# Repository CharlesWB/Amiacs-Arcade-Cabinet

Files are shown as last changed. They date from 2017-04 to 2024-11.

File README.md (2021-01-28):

# Amiacs Arcade Cabinet

My adventures in creating a custom arcade cabinet.

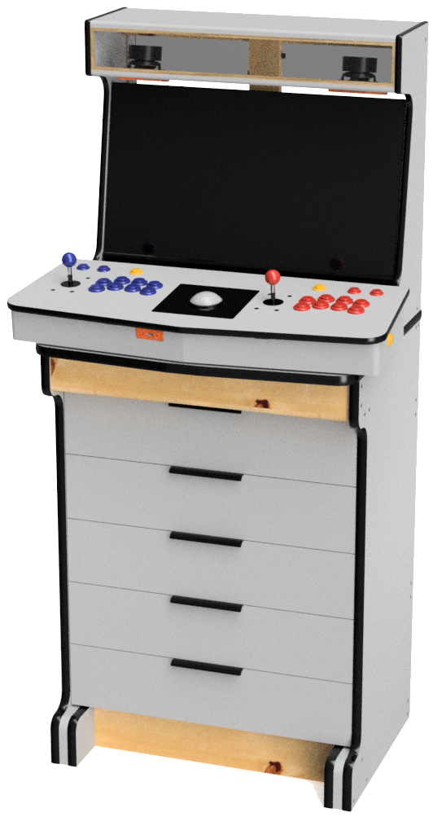
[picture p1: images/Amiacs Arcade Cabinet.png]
Model of Amiacs Arcade Cabinet


## License

The cabinet of this project is licensed under the [Creative Commons Attribution-NonCommercial-ShareAlike 4.0 International (CC BY-NC-SA 4.0) license](https://creativecommons.org/licenses/by-sa/4.0/), and the source code is licensed under the [MIT license](http://opensource.org/licenses/mit-license.php).

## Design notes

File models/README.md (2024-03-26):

# Models

This folder contains various "models" used to create the Amiacs arcade cabinet. Such as 3D models, artwork, and Fritzing diagrams.

## Amiacs Arcade Cabinet Prototype.skp

3D CAD model of the original prototype cabinet. Created using [SketchUp](https://www.sketchup.com/).

## Amiacs Arcade Cabinet v32.step

A STEP file format export of the CAD model prior to the removal of the export functionality from the personal version of AutoDesk Fusion 360. This export occurred at v32 of the Fusion 360 model.

## Amiacs Arcade.fzz

Fritzing diagram representing the wiring of all the components in the cabinet. Created using [Fritzing](https://fritzing.org/).

## Button Labels.svg

Vector images for the labels that are placed directly on the control panel buttons. Created using [Inkscape](https://inkscape.org/).

### Fonts Used

* [Game Played](https://www.dafont.com/game-played.font) for button text.
* [Restroom](https://www.dafont.com/restroom.font) for one and two player button labels (character 'G').
* [Fire](https://www.dafont.com/fire.font) for hotkey button symbol (character 't').

In Inkscape, Document Resources also has a list of the fonts used in the file.

### Usage

* Designed for import to [Cricut Design Space](https://cricut.com/) for cutting.
* Cut from black vinyl with adhesive backing.
* The circle of each label is used for aligning the text on the actual button.

*Cricut Design Space Import*

1. In Inkscape, select all text objects and use Path -> Object to Path.
    * Cricut Design Space didn't import text objects.
    * Use Ctrl to select into a group.
2. Upload as image to Cricut Design Space.
3. Change size of top level group to match Inkscape size.
    * Not sure why size is incorrect. Possibly due to metric/inch scaling.
    * Technically Inkscape size is .1 mm larger due to stroke thickness.
4. Ungroup top level group.
5. Select each button label group and Attach to keep the shapes together.

## Cabinet Artwork.svg

Vector image used for describing the cabinet graphics. Created using [Inkscape](https://inkscape.org/).

### Fonts Used

* [Game Played](https://www.dafont.com/game-played.font) for button text and console labels.
* [Fire](https://www.dafont.com/fire.font) for hotkey button symbol (character 't')
* [Aurebesh](https://www.dafont.com/aurebesh.font) for the secret names.
* [Back to the Future 2002](https://www.dafont.com/back-to-the-future.font) for the representation of the logo on the marquee. This is not meant to be the final look.
* Arial for drawing notes and reference dimensions.

In Inkscape, Document Resources also has a list of the fonts used in the file.

## Cabinet Labels.svg

Vector images of various labels placed on the cabinet. Created using [Inkscape](https://inkscape.org/).

### Fonts Used

* Arial for all text.

In Inkscape, Document Resources also has a list of the fonts used in the file.

### Usage

I'm using an adhesive backed vinyl. Trying to get the best durability and adhesion.

## Test Amiacs Light Controller.fzz

Fritzing breadboard diagram for testing the various LEDs of the cabinet. Created using [Fritzing](https://fritzing.org/).

## Test MCP23017 Arcade Button LEDs.fzz

Fritzing breadboard diagram for testing control of the button LEDs using an MCP23017. Created using [Fritzing](https://fritzing.org/).

This was an early prototype for controlling multiple LEDs using two pins on the Arduino. This is not used in the current cabinet design.

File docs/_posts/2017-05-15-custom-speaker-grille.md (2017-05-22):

---
layout: post
title:  "Custom Speaker Grille"
date:   2017-05-15 18:00:00
excerpt_separator: <!--more-->
---
When I bought the small 3" (78 mm) [speakers](http://a.co/ejMOJVP) I hadn't found a speaker grille that would fit.
Every once in a while I'd look but the smallest I could find was 3.5" (90 mm).

I had recently purchased a [3D printer](http://a.co/9hegcnT) and I realized that I finally had a practical use for it.
<!--more-->

I created a 3D printable speaker grille. Nothing fancy, a rectangular part with four mounting holes and a lot
of holes in a circular pattern. It's a component in the
[SketchUp model]({{ site.github.repository_url }}/tree/master/models/).

3D printing is still new to me so getting that first layer to stick took some work. Especially all those circles.
It wasn't perfect but eventually I printed on a glass sheet which gave me a very smooth surface finish.
Even though nobody really sees it given where it is on the cabinet.

The parameters I used to print it are: 0.2 mm layer height, 0.8 mm wall thickness, and 20% infill.

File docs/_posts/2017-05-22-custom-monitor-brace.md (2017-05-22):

---
layout: post
title:  "Custom Monitor Brace"
date:   2017-05-22 16:45:00
excerpt_separator: <!--more-->
---
As I noted in a previous post the monitor mount works fine, but because it only holds the monitor at the bottom
the top of the monitor can move around.
<!--more-->

At the time I did a quick fix by placing a piece of MDF behind the top of the monitor. This would stop
the monitor from being pushed too far back. (Because I know the kids will touch the monitor to point
at things.) This piece is not shown in the
[SketchUp model]({{ site.github.repository_url }}/tree/master/models/).

This still allowed the monitor the move forward and side to side so I tried an even cheaper fix by pushing foam
around the top corners. It worked well enough to get through play testing.

Now that I have a 3D printer I designed a custom corner brace. One each at the top corners holds the monitor in place.
No more flopping around. Like the custom speaker grille it's a component in the SketchUp model.

The parameters I used to print it are: 0.2 mm layer height, 0.8 mm wall thickness, and 20% infill.

This cabinet still has the piece of MDF at the center of the monitor so I don't know yet if that's actually needed.
Maybe with a future build I'll leave that out and try it.

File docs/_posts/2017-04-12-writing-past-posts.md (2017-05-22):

---
layout: post
title:  "Writing Past Posts"
date:   2017-04-12 18:00:00
---
I started this project several months ago. And at the time I did not write any posts.
I didn't even have this blog/Github project.
I've decided to go back in time and write those posts.

So over the coming weeks (or months) you'll see me creating those past posts as well as current posts.

Hopefully that's not too confusing. Because current posts may reference the as yet unwritten past posts.
I'm sure it'll work out in the end.

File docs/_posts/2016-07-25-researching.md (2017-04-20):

---
layout: post
title:  "Researching"
date:   2016-07-25 12:00:00
excerpt_separator: <!--more-->
---
Okay, so I want an 80's style arcade cabinet with buttons, joystick, trackball, and flashing lights.
What does that actually involve? Time to research what my options are.
<!--more-->

The pictures and discussions on [Coding Horror's post](https://blog.codinghorror.com/the-raspberry-pi-has-revolutionized-emulation/) defined most of my choices.

Here's the wishlist I came up with:
* Controls for two players. Fun for the whole family. At least two of them anyway.
* Buttons that light up. Flashing lights are required to make it feel like an arcade.
* Joysticks with ball shaped handle. Instead of the bat shape. Just because it looks right.
* Trackball. How else can you play Centipede?
* Trackball that lights up. Need more flashing lights.
* Steering wheel. How else can you play Outrun?
* Insert coin slots. For authenticity.
* Custom graphics. More authenticity.
* Bar top size. Trying for something semi-portable.

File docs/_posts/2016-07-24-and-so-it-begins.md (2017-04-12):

---
layout: post
title:  "And So It Begins..."
date:   2016-07-24 12:00:00
---
Years ago I thought about building a MAME arcade machine. Which at the time meant a big, boxy computer and a big, boxy CRT monitor. I never got around to it.

Then Coding Horror wrote his post about [Raspberry Pi revolutionizing emulation](https://blog.codinghorror.com/the-raspberry-pi-has-revolutionized-emulation/).
Suddenly the desire to relive all those 80's arcade games came back. And to have an actual 80's style arcade cabinet.
Buttons, joystick, trackball, flashing lights, the whole works.

And so it begins...

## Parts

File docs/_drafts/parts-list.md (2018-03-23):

---
layout: post
title:  "Parts List"
date:   2018-02-25 12:00:00
---
|Part|Link|Cost|
|---|---|---|
|Electric ICE-T™ Deluxe RGB Arcade Trackball V2.5|http://groovygamegear.com/webstore/index.php?main_page=product_info&cPath=74&products_id=270|$116.95|
|Trackball Mounting Kit - 3"|http://groovygamegear.com/webstore/index.php?main_page=product_info&cPath=74&products_id=314|$13.95|
|CanaKit Raspberry Pi 3 with 2.5A Micro USB Power Supply|http://a.co/fu1tPRN|$42.99|
|Micro SD Card 32 GB||$13.00|
|Acer R240HY bidx 23.8-Inch IPS Monitor|http://a.co/5v14bSI|$129.99|

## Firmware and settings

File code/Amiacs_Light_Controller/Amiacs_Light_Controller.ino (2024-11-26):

/*
Ideas:
- I2C command data and related methods could be a separate class.
- The player buttons flicker when using FastLED.show() and no changes were made.
  Is that an error in TLC5947SingleColorController or normal? Right now this code gets
  around this by not calling show() when no colors change.
*/

#define FASTLED_INTERNAL

#include <Adafruit_TLC5947.h>
#include <FastLED.h>
#include <Wire.h>
#include "SingleTriColorLEDController.h"
#include "TLC5947SingleColorController.h"


// General definitions.
// Can only be 2. No other values have been implemented.
#define NUM_PLAYERS 2
// Can only be 1. No other values have been implemented.
#define NUM_TRACKBALLS 1
// Can only be 2. No other values have been implemented.
#define NUM_AMBIENT_LEDS 2


// Pin definitions.
#define PLAYER_LIGHTS_LATCH_PIN 10
#define PLAYER_LIGHTS_DATA_PIN 12
#define PLAYER_LIGHTS_CLOCK_PIN 13
#define PLAYER_LIGHTS_OUTPUT_ENABLE_PIN = 8
#define TRACKBALL_RED_PIN 3
#define TRACKBALL_GREEN_PIN 5
#define TRACKBALL_BLUE_PIN 6
#define MARQUEE_LIGHT_PIN 9
#define AMBIENT_LIGHT_DATA_PIN 11
#define AMBIENT_LIGHT_CLOCK_PIN 13
#define BRIGHTNESS_PIN A7


// Player button pin numbers for the Adafruit TLC5947.
#define NUM_PLAYER_LIGHTS 24
#define PLAYER1_LIGHT_B 0
#define PLAYER1_LIGHT_A 1
#define PLAYER1_LIGHT_Y 2
#define PLAYER1_LIGHT_X 3
#define PLAYER1_LIGHT_L2 4
#define PLAYER1_LIGHT_R2 5
#define PLAYER1_LIGHT_L1 6
#define PLAYER1_LIGHT_R1 7
#define PLAYER1_LIGHT_SELECT 8
#define PLAYER1_LIGHT_START 9
#define PLAYER1_LIGHT_COMMAND 10
#define PLAYER1_LIGHT_HOTKEY 11
#define PLAYER2_LIGHT_B 12
#define PLAYER2_LIGHT_A 13
#define PLAYER2_LIGHT_Y 14
#define PLAYER2_LIGHT_X 15
#define PLAYER2_LIGHT_L2 16
#define PLAYER2_LIGHT_R2 17
#define PLAYER2_LIGHT_L1 18
#define PLAYER2_LIGHT_R1 19
#define PLAYER2_LIGHT_SELECT 20
#define PLAYER2_LIGHT_START 21
#define PLAYER2_LIGHT_COMMAND 22
#define PLAYER2_LIGHT_HOTKEY 23

#define PLAYER_ALL_LIGHTS_LAYOUT_ROWS 3
#define PLAYER_ALL_LIGHTS_LAYOUT_COLUMNS 11
#define PLAYER1_ALL_LIGHTS_LAYOUT_COLUMNS 6
#define PLAYER2_ALL_LIGHTS_LAYOUT_COLUMNS 5

int playerAllLightLayout[PLAYER_ALL_LIGHTS_LAYOUT_ROWS][PLAYER_ALL_LIGHTS_LAYOUT_COLUMNS] =
{
  {-1, PLAYER1_LIGHT_SELECT, PLAYER1_LIGHT_START, PLAYER1_LIGHT_COMMAND, -1, -1, PLAYER2_LIGHT_COMMAND, -1, PLAYER2_LIGHT_SELECT, PLAYER2_LIGHT_START, -1},
  {-1, -1, PLAYER1_LIGHT_Y, PLAYER1_LIGHT_X, PLAYER1_LIGHT_L2, PLAYER1_LIGHT_R2, PLAYER2_LIGHT_Y, PLAYER2_LIGHT_X, PLAYER2_LIGHT_L2, PLAYER2_LIGHT_R2, -1},
  {PLAYER1_LIGHT_HOTKEY, -1, PLAYER1_LIGHT_B, PLAYER1_LIGHT_A, PLAYER1_LIGHT_L1, PLAYER1_LIGHT_R1, PLAYER2_LIGHT_B, PLAYER2_LIGHT_A, PLAYER2_LIGHT_L1, PLAYER2_LIGHT_R1, PLAYER2_LIGHT_HOTKEY}
};

#define PLAYER_PRIMARY_LIGHTS_LAYOUT_ROWS 2
#define PLAYER_PRIMARY_LIGHTS_LAYOUT_COLUMNS 8

int playerPrimaryLightLayout[PLAYER_PRIMARY_LIGHTS_LAYOUT_ROWS][PLAYER_PRIMARY_LIGHTS_LAYOUT_COLUMNS] =
{
  {PLAYER1_LIGHT_Y, PLAYER1_LIGHT_X, PLAYER1_LIGHT_L2, PLAYER1_LIGHT_R2, PLAYER2_LIGHT_Y, PLAYER2_LIGHT_X, PLAYER2_LIGHT_L2, PLAYER2_LIGHT_R2},
  {PLAYER1_LIGHT_B, PLAYER1_LIGHT_A, PLAYER1_LIGHT_L1, PLAYER1_LIGHT_R1, PLAYER2_LIGHT_B, PLAYER2_LIGHT_A, PLAYER2_LIGHT_L1, PLAYER2_LIGHT_R1}
};

// Although the color of the player lights is defined by the button plastic,
// for FastLED the player light color is white so that it is fully lit.
const CHSV playerLightColor = CHSV(0, 0, 255);

const CHSV defaultSystemColor = CHSV(24, 255, 255);
CRGB playerColors[NUM_PLAYERS] = {CRGB::Blue, CRGB::Red};
CHSV playerColorsHSV[NUM_PLAYERS] = {rgb2hsv_approximate(playerColors[0]), rgb2hsv_approximate(playerColors[1])};

// The intent for this palette is to cycle between the player colors.
CRGBPalette16 playerColorPalette = CRGBPalette16(
  playerColors[0], playerColors[0], playerColors[0], playerColors[0],
  playerColors[0], playerColors[0], playerColors[0], playerColors[0],
  playerColors[1], playerColors[1], playerColors[1], playerColors[1],
  playerColors[1], playerColors[1], playerColors[1], playerColors[1]
);

CRGB playerLights[NUM_PLAYER_LIGHTS];
CRGB trackballs[NUM_TRACKBALLS];
CRGB ambientLights[NUM_AMBIENT_LEDS];


// I2C communications between the Arduino and the Raspberry Pi.
// Data format:
// - 1 byte for the command. The command value is the same as the DisplayMode enum.
// - Data for game running display mode:
//   - 12 bytes for player 1 lights. In same order as Adafruit TLC5947 pins defined above. Non-zero value indicates light is on.
//   - 12 bytes for player 2 lights. In same order as Adafruit TLC5947 pins defined above. Non-zero value indicates light is on.
//   - 1 byte for trackball. Non-zero value indicates trackball light is on.
//   - 1 byte to indicate that the game has two separate player controls.
// Any additional data is read but ignored.
#define SLAVE_ADDRESS 0x07
#define COMMAND_ARRAY_SIZE NUM_PLAYER_LIGHTS + NUM_TRACKBALLS + 1
#define COMMAND_TRACKBALL_INDEX COMMAND_ARRAY_SIZE - 2
#define COMMAND_TWO_CONTROLS_INDEX COMMAND_ARRAY_SIZE - 1
byte command = 0;
byte commandData[COMMAND_ARRAY_SIZE];


// These values match what is found in Amiacs-Event-Processor.py.
enum DisplayMode {
  // Mode used while system starts.
  STARTING = 0,
  // Mode used when Emulation Station displays a screensaver.
  ATTRACT = 1,
  // Mode used when the Emulation Station is running.
  EMULATION_STATION = 2,
  // Mode used when a game system is running.
  GAME_RUNNING = 3,
};

DisplayMode displayMode = STARTING;

// For each DisplayMode, identify if an initialization must be done while running in loop.
// NOTE: This is manually sized to match the number of DisplayModes.
int initializeDisplayMode[] = {false, true, true, true};

// The attract DisplayMode has an additional initialization step for the brightness.
bool initializeAttractDisplayModeBrightness = true;

enum AttractDisplayMode {
  RANDOM_BLINK,
  CYLON,
  IN_TO_CENTER,
  NUM_ATTRACT_DISPLAY_MODES,
};

AttractDisplayMode attractDisplayMode = random8(NUM_ATTRACT_DISPLAY_MODES);


void setup() {
  Serial.begin(9600);

  // There's a short delay between when the Arduino starts and when the button
  // encoder and the Adafruit TLC5947 boards get power from the Raspberry Pi.
  // We'll wait for that so that the TLC5947 will be properly initialized.
  delay(5000);

  SetBrightness();

  SetupPlayerLights();
  SetupTrackballLights();
  SetupAmbientLights();
  SetupMarqueeLights();

  TestLightsDuringSetup();

  Wire.begin(SLAVE_ADDRESS);
  Wire.onReceive(CommandReceiveEvent);

  SetLightsToSystemDefaultColor();

  FastLED.show();
}

void loop() {
  switch(displayMode) {
    case STARTING:
      LoopStartingDisplayMode();
      break;
    case ATTRACT:
      LoopAttractDisplayMode();
      break;
    case EMULATION_STATION:
      LoopEmulationStationDisplayMode();
      break;
    case GAME_RUNNING:
      LoopGameRunningDisplayMode();
      break;
  }
}


// The display mode during startup is a type of attract mode.
// The lights are expected to have been turned on to their default colors prior to this.
// This will fade the brightness in and out at an increasing rate then pause before switching to Emulation Station mode.
// The typical time from power on to Emulation Station start is about one minute.
void LoopStartingDisplayMode() {
  static unsigned long startTime = millis();

  static unsigned long startingStepTimeline[] = {0, 5000, 9900, 14700, 19200, 23200, 26700, 29600, 31900, 33400, 34200, 34800, 35400, 36000, 36400, 45000};
  uint8_t stepCount = (sizeof(startingStepTimeline) / sizeof(startingStepTimeline[0]));

  SetBrightness();

  unsigned long now = millis() - startTime;
  uint8_t step = 0;
  for(uint8_t i = 0; i < stepCount; i++) {
    if(now > startingStepTimeline[i]) {
      step = i;
    }
  }

  if(step < stepCount - 2) {
    uint8_t frame = map(now, startingStepTimeline[step], startingStepTimeline[step + 1], 255, 0);

    // Offset the frame by 128 so that the brightness starts at 255.
    uint8_t brightness = quadwave8(frame + 128);

    if(playerLights[0] != CHSV(playerLightColor.hue, playerLightColor.sat, brightness)) {
      fill_solid(playerLights, NUM_PLAYER_LIGHTS, CHSV(playerLightColor.hue, playerLightColor.sat, brightness));
      fill_solid(trackballs, NUM_TRACKBALLS, CHSV(defaultSystemColor.hue, defaultSystemColor.sat, brightness));
      fill_solid(ambientLights, NUM_AMBIENT_LEDS, CHSV(defaultSystemColor.hue, defaultSystemColor.sat, brightness));
      FastLED.show();
      SetMarqueeBrightness(brightness);
    }
  }
  else if(step < stepCount - 1) {
    if(playerLights[0] != playerLightColor) {
      fill_solid(playerLights, NUM_PLAYER_LIGHTS, playerLightColor);
      fill_solid(trackballs, NUM_TRACKBALLS, defaultSystemColor);
      fill_solid(ambientLights, NUM_AMBIENT_LEDS, defaultSystemColor);
      FastLED.show();
    }
  }
  else {
    displayMode = EMULATION_STATION;
    initializeDisplayMode[EMULATION_STATION] = true;
  }
}

void LoopEmulationStationDisplayMode() {
  static unsigned long startTime = millis();

  SetBrightness();

  if(initializeDisplayMode[EMULATION_STATION]) {
    startTime = millis();

    EmulationStationDisplayModeInitialize();

    initializeDisplayMode[EMULATION_STATION] = false;
  }
}

void EmulationStationDisplayModeInitialize() {
  fill_solid(playerLights, NUM_PLAYER_LIGHTS, playerLightColor);

  playerLights[PLAYER1_LIGHT_L2] = CRGB::Black;
  playerLights[PLAYER1_LIGHT_R2] = CRGB::Black;
  playerLights[PLAYER1_LIGHT_COMMAND] = CRGB::Black;
  playerLights[PLAYER1_LIGHT_HOTKEY] = CRGB::Black;
  playerLights[PLAYER2_LIGHT_L2] = CRGB::Black;
  playerLights[PLAYER2_LIGHT_R2] = CRGB::Black;
  playerLights[PLAYER2_LIGHT_COMMAND] = CRGB::Black;
  playerLights[PLAYER2_LIGHT_HOTKEY] = CRGB::Black;

  fill_solid(trackballs, NUM_TRACKBALLS, CRGB::Black);

  fill_solid(ambientLights, NUM_AMBIENT_LEDS, defaultSystemColor);

  FastLED.show();
}

void LoopGameRunningDisplayMode() {
  SetBrightness();

  if(initializeDisplayMode[GAME_RUNNING]) {
    GameRunningDisplayModeInitialize();

    initializeDisplayMode[GAME_RUNNING] = false;
  }

  if(CommandIsTrackballOn() && CommandIsTwoControllerGame()) {
    CycleTrackballBetweenPlayerColors();
  }
}

void GameRunningDisplayModeInitialize() {
  for(int light = 0; light < NUM_PLAYER_LIGHTS; light++) {
    if(commandData[light] != 0) {
      playerLights[light] = playerLightColor;
    }
    else {
      playerLights[light] = CRGB::Black;
    }
  }

  if(CommandIsTrackballOn()) {
    fill_solid(trackballs, NUM_TRACKBALLS, playerColors[0]);
  }
  else {
    fill_solid(trackballs, NUM_TRACKBALLS, CRGB::Black);
  }

  fill_solid(ambientLights, NUM_AMBIENT_LEDS, defaultSystemColor);

  FastLED.show();
}

// Randomly alternate between the various attract display modes.
// Dim the lights over time. At a low level completely turn off the lights.
void LoopAttractDisplayMode() {
  const static unsigned long duration = 120000;
  const static unsigned long dimmingDuration = 2 * duration;

  static unsigned long startTime = millis();
  static unsigned long dimmingStartTime = millis();

  static float brightnessFactor = 1;

  if(initializeAttractDisplayModeBrightness) {
    dimmingStartTime = millis();

    brightnessFactor = 1;

    initializeAttractDisplayModeBrightness = false;
  }

  if(initializeDisplayMode[ATTRACT]) {
    startTime = millis();

    AttractDisplayModeInitialize();

    initializeDisplayMode[ATTRACT] = false;
  }

  if(brightnessFactor > .2) {
    SetBrightness(brightnessFactor);

    unsigned long dimmingNow = millis() - dimmingStartTime;
    if(dimmingNow > dimmingDuration) {
      brightnessFactor *= .6;
      dimmingStartTime = millis();
    }

    unsigned long now = millis() - startTime;
    if(now <= duration) {
      if(attractDisplayMode == RANDOM_BLINK) {
        AttractDisplayModeRandomBlink();
      }
      else if(attractDisplayMode == CYLON) {
        AttractDisplayModeCylon();
      }
      else if(attractDisplayMode == IN_TO_CENTER) {
        AttractDisplayModeInToCenter();
      }

      FastLED.show();
    }
    else {
      AttractDisplayMode nextAttractDisplayMode = random8(NUM_ATTRACT_DISPLAY_MODES);
      if(nextAttractDisplayMode != attractDisplayMode) {
        attractDisplayMode = nextAttractDisplayMode;
        initializeDisplayMode[ATTRACT] = true;
      }
    }
  }
  else {
    fill_solid(playerLights, NUM_PLAYER_LIGHTS, CRGB::Black);
    fill_solid(trackballs, NUM_TRACKBALLS, CRGB::Black);
    fill_solid(ambientLights, NUM_AMBIENT_LEDS, CRGB::Black);
    SetMarqueeBrightness(0);

    FastLED.show();
  }
}

void AttractDisplayModeInitialize() {
  fill_solid(playerLights, NUM_PLAYER_LIGHTS, CRGB::Black);
  fill_solid(trackballs, NUM_TRACKBALLS, CRGB::Black);
  fill_solid(ambientLights, NUM_AMBIENT_LEDS, CRGB::Black);

  FastLED.show();
}

// Cycle columns in to the center and back, fading out the other columns.
// Fade the trackball in sync with the cycle.
// Fade in and out each side of the ambient lights to match the cycling player colors.
void AttractDisplayModeInToCenter() {
  const static unsigned long duration = 2400;

  static unsigned long startTime = millis();

  unsigned long now = millis() - startTime;

  unsigned long elapsed = now - (duration * (now / duration));
  int player1Column = elapsed / (duration / (2 * PLAYER1_ALL_LIGHTS_LAYOUT_COLUMNS));
  if(player1Column >= PLAYER1_ALL_LIGHTS_LAYOUT_COLUMNS) {
    player1Column = (2 * PLAYER1_ALL_LIGHTS_LAYOUT_COLUMNS) - player1Column - 1;
  }

  int player2Column = elapsed / (duration / (2 * PLAYER2_ALL_LIGHTS_LAYOUT_COLUMNS));
  if(player2Column >= PLAYER2_ALL_LIGHTS_LAYOUT_COLUMNS) {
    player2Column = (2 * PLAYER2_ALL_LIGHTS_LAYOUT_COLUMNS) - player2Column - 1;
  }

  for(uint8_t column = 0; column < PLAYER_ALL_LIGHTS_LAYOUT_COLUMNS; column++) {
    for(uint8_t row = 0; row < PLAYER_ALL_LIGHTS_LAYOUT_ROWS; row++) {
      if(playerAllLightLayout[row][column] >= 0) {
        if(column == player1Column || column == PLAYER_ALL_LIGHTS_LAYOUT_COLUMNS - player2Column - 1) {
          playerLights[playerAllLightLayout[row][column]] = playerLightColor;
        }
        else {
          playerLights[playerAllLightLayout[row][column]].nscale8(250);
        }
      }
    }
  }

  if(elapsed > duration / 2) {
    elapsed = duration - elapsed;
  }
  fill_solid(trackballs, NUM_TRACKBALLS, CHSV(defaultSystemColor.hue, defaultSystemColor.sat, map(elapsed, 0, duration / 2, 20, 255)));

  ambientLights[0] = CHSV(playerColorsHSV[0].hue, playerColorsHSV[0].sat, map(elapsed, 0, duration / 2, 50, 255));
  ambientLights[1] = CHSV(playerColorsHSV[1].hue, playerColorsHSV[1].sat, map(elapsed, 0, duration / 2, 50, 255));
}

// Cycle back and forth through the columns, fading out the other columns.
// Cycle the trackball between player colors.
// Fade in and out each side of the ambient lights to match the cycling player colors.
// Duration is for the full cycle, which is divided into four parts.
// First part moves left to right through player 1.
// Second part moves left to right through player 2.
// Third part moves right to left through player 2.
// Fourth part moves right to left through player 1.
// Note that the player columns may not be an equal amount. So duration is not evenly divided between the two players.
void AttractDisplayModeCylon() {
  const static unsigned long durationPerColumn = 125;
  const static unsigned long duration = durationPerColumn * 2 * PLAYER_ALL_LIGHTS_LAYOUT_COLUMNS;
  const static unsigned long player1Duration = durationPerColumn * PLAYER1_ALL_LIGHTS_LAYOUT_COLUMNS;
  const static unsigned long player2Duration = durationPerColumn * PLAYER2_ALL_LIGHTS_LAYOUT_COLUMNS;

  static unsigned long startTime = millis();

  unsigned long now = millis() - startTime;

  unsigned long elapsed = now - (duration * (now / duration));
  int playerColumn = elapsed / (duration / (2 * PLAYER_ALL_LIGHTS_LAYOUT_COLUMNS));
  if(playerColumn >= PLAYER_ALL_LIGHTS_LAYOUT_COLUMNS) {
    playerColumn = (2 * PLAYER_ALL_LIGHTS_LAYOUT_COLUMNS) - playerColumn - 1;
  }

  for(uint8_t column = 0; column < PLAYER_ALL_LIGHTS_LAYOUT_COLUMNS; column++) {
    for(uint8_t row = 0; row < PLAYER_ALL_LIGHTS_LAYOUT_ROWS; row++) {
      if(playerAllLightLayout[row][column] >= 0) {
        if(playerColumn == column) {
          playerLights[playerAllLightLayout[row][column]] = playerLightColor;
        }
        else {
          playerLights[playerAllLightLayout[row][column]].nscale8(250);
        }
      }
    }
  }

  if(playerColumn < PLAYER1_ALL_LIGHTS_LAYOUT_COLUMNS) {
    fill_solid(trackballs, NUM_TRACKBALLS, playerColors[0]);

    // Example:
    // If duration is 100 and player columns are equal then
    // player 1 runs from 0 to 25 (player1Duration) and 75 (delta is 2 * player2Duration) to 100.
    // This is converted to 25 (player1Duration) to 0 and back to 25.
    unsigned long playerElapsed = player1Duration - elapsed;
    if(elapsed >= player1Duration) {
      playerElapsed = player1Duration - (duration - elapsed);
    }

    ambientLights[0] = CHSV(playerColorsHSV[0].hue, playerColorsHSV[0].sat, map(playerElapsed, 0, player1Duration, 50, 255));
    ambientLights[1] = CRGB::Black;
  }
  else {
    fill_solid(trackballs, NUM_TRACKBALLS, playerColors[1]);

    // Example:
    // If duration is 100 and player columns are equal then
    // player 2 runs from 25 (player1Duration) to 75 (delta is 2 * player2Duration).
    // This is converted to 0 to 25 (player2Duration) and back to 0.
    unsigned long playerElapsed = elapsed - player1Duration;
    if(elapsed >= duration - player1Duration - player2Duration) {
      playerElapsed = duration - elapsed - player1Duration;
    }

    ambientLights[0] = CRGB::Black;
    ambientLights[1] = CHSV(playerColorsHSV[1].hue, playerColorsHSV[1].sat, map(playerElapsed, 0, player2Duration, 50, 255));
  }
}

// Randomly blink the player lights.
// Randomly change the color of the trackball.
// Randomly change the color of the ambient per side.
void AttractDisplayModeRandomBlink() {
  static unsigned long startTime = millis();

  int playerLight = random8(NUM_PLAYER_LIGHTS);
  int on = random8(100);
  if(on > 50) {
    playerLights[playerLight] = playerLightColor;
  }
  else {
    playerLights[playerLight] = CRGB::Black;
  }

  if(millis() - startTime > 500) {
    CRGB color = ColorFromPalette(RainbowColors_p, random8(240), 255, LINEARBLEND);
    fill_solid(trackballs, NUM_TRACKBALLS, color);

    ambientLights[0] = ColorFromPalette(RainbowColors_p, random8(240), 255, LINEARBLEND);
    ambientLights[1] = ColorFromPalette(RainbowColors_p, random8(240), 255, LINEARBLEND);

    startTime = millis();
  }
}


// *** I2C Command Processing ***

void CommandReceiveEvent(int byteCount) {
  if(Wire.available()) {
    command = Wire.read();

    memset(commandData, 0, sizeof(commandData));

    int dataIndex = 0;
    while(Wire.available()) {
      byte data = Wire.read();

      // The command data array is a certain size. I'm not going to
      // assume the data size matches the array size. Any excess data
      // will simply be read and ignored.
      if(dataIndex < COMMAND_ARRAY_SIZE) {
        commandData[dataIndex] = data;
      }

      dataIndex++;
    }

    displayMode = (DisplayMode)command;
    initializeDisplayMode[displayMode] = true;
    initializeAttractDisplayModeBrightness = true;
  }
}

bool CommandIsTrackballOn() {
  return commandData[COMMAND_TRACKBALL_INDEX] != 0;
}

bool CommandIsTwoControllerGame() {
  return commandData[COMMAND_TWO_CONTROLS_INDEX] != 0;
}


// *** Cabinet Lights ***

void SetLightsToSystemDefaultColor() {
  fill_solid(playerLights, NUM_PLAYER_LIGHTS, playerLightColor);
  fill_solid(trackballs, NUM_TRACKBALLS, defaultSystemColor);
  fill_solid(ambientLights, NUM_AMBIENT_LEDS, defaultSystemColor);
  FastLED.show();
  SetMarqueeBrightness(GetBrightness());
}

void TestLightsDuringSetup() {
  fill_solid(playerLights, NUM_PLAYER_LIGHTS, CRGB::White);

  fill_solid(trackballs, NUM_TRACKBALLS, CRGB::Red);
  fill_solid(ambientLights, NUM_AMBIENT_LEDS, CRGB::Red);
  FastLED.show();
  delay(1000);

  fill_solid(trackballs, NUM_TRACKBALLS, CRGB::Green);
  fill_solid(ambientLights, NUM_AMBIENT_LEDS, CRGB::Green);
  FastLED.show();
  delay(1000);

  fill_solid(trackballs, NUM_TRACKBALLS, CRGB::Blue);
  fill_solid(ambientLights, NUM_AMBIENT_LEDS, CRGB::Blue);
  FastLED.show();
  delay(1000);
}


// *** Player Lights ***

void SetupPlayerLights() {
  static TLC5947SingleColorController<PLAYER_LIGHTS_DATA_PIN, PLAYER_LIGHTS_CLOCK_PIN, PLAYER_LIGHTS_LATCH_PIN> playerLightController;
  FastLED.addLeds(&playerLightController, playerLights, NUM_PLAYER_LIGHTS);
}


// *** Trackball Lights ***

void SetupTrackballLights() {
  static SingleTriColorLEDController<TRACKBALL_RED_PIN, TRACKBALL_GREEN_PIN, TRACKBALL_BLUE_PIN> trackballLEDController;
  FastLED.addLeds(&trackballLEDController, trackballs, NUM_TRACKBALLS).setCorrection(0xC0FFE0);
}

void CycleTrackballBetweenPlayerColors() {
  static unsigned long startTime = millis();

  static uint8_t playerColorPaletteIndex = 0;

  // 40 ms per step is approximately 10 seconds over 256 steps.
  if(millis() - startTime > 40) {
    fill_solid(trackballs, NUM_TRACKBALLS, ColorFromPalette(playerColorPalette, playerColorPaletteIndex));

    // TODO Remove the hard-coding of the trackball LEDs index. Or resolve flicker when updating player lights using FastLED.show().
    FastLED[1].showLedsInternal(GetBrightness());

    playerColorPaletteIndex++;

    startTime = millis();
  }
}


// *** Ambient Lights ***

void SetupAmbientLights() {
  FastLED.addLeds<P9813, AMBIENT_LIGHT_DATA_PIN, AMBIENT_LIGHT_CLOCK_PIN, RBG>(ambientLights, NUM_AMBIENT_LEDS).setCorrection(0xFF90FF);
}


// *** Marquee Lights ***

void SetupMarqueeLights() {
  pinMode(MARQUEE_LIGHT_PIN, OUTPUT);
}

void SetMarqueeBrightness(uint8_t brightness) {
  analogWrite(MARQUEE_LIGHT_PIN, brightness);
}


// *** Brightness ***
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

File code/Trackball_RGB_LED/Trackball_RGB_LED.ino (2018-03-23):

// Note that brown wire is for 5V.

// Define Pins
#define RED 3
#define GREEN 5
#define BLUE 6

#define delayTime 10 // fading time between colors


void setup()
{
  pinMode(RED, OUTPUT);
  pinMode(GREEN, OUTPUT);
  pinMode(BLUE, OUTPUT);
  digitalWrite(RED, HIGH);
  digitalWrite(GREEN, HIGH);
  digitalWrite(BLUE, HIGH);
}

// define variables
int redValue;
int greenValue;
int blueValue;


// main loop
void loop()
{
  cycleSingleColor(GREEN);
  cycleSingleColor(BLUE);
  turnOnSingleColor(RED);
  delay(1000);

  redValue = 255; // choose a value between 1 and 255 to change the color.
  greenValue = 0;
  blueValue = 0;
  for(int i = 0; i < 255; i += 1) // fades out red bring green full when i=255
  {
    redValue -= 1;
    greenValue += 1;
    analogWrite(RED, 255 - redValue);
    analogWrite(GREEN, 255 - greenValue);
    delay(delayTime * 5);
  }

  redValue = 0;
  greenValue = 255;
  blueValue = 0;
  for(int i = 0; i < 255; i += 1)  // fades out green bring blue full when i=255
  {
    greenValue -= 1;
    blueValue += 1;
    analogWrite(GREEN, 255 - greenValue);
    analogWrite(BLUE, 255 - blueValue);
    delay(delayTime * 5);
  }

  redValue = 0;
  greenValue = 0;
  blueValue = 255;
  for(int i = 0; i < 255; i += 1)  // fades out blue bring red full when i=255
  {
  redValue += 1;
  blueValue -= 1;
  analogWrite(RED, 255 - redValue);
  analogWrite(BLUE, 255 - blueValue);
  delay(delayTime * 5);
  }

  turnOffSingleColor(RED);
}


void cycleSingleColor(int pin)
{
  for(int i = 0; i < 255; i += 1)
  {
    analogWrite(pin, 255 - i);
    delay(delayTime);
  }

  for(int i = 255; i >= 0; i -= 1)
  {
    analogWrite(pin, 255 - i);
    delay(delayTime);
  }
}

void turnOnSingleColor(int pin)
{
  for(int i = 0; i < 255; i += 1)
  {
    analogWrite(pin, 255 - i);
    delay(delayTime);
  }
}

void turnOffSingleColor(int pin)
{
  for(int i = 255; i >= 0; i -= 1)
  {
    analogWrite(pin, 255 - i);
    delay(delayTime);
  }
}

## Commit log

2017-05-07 Add an Arduino sketch for testing the control of button LEDs.
2017-05-07 Add comment for the site that inspired the LED patterns.
2017-05-14 Add 3D printable speaker grille to the SketchUp model. Update gitignore for SketchUp backup files.
2017-05-22 Add a 3D printable monitor corner brace. Add post explaining writing past posts. Add post for the custom speaker grille. Add post for the custom monitor brace.
2017-12-03 Shift base's front component back so that screws do not interfere with t-molding slot.
2017-12-09 Adjust the position of the brackets mounting the base's front.
2018-03-23 Add Arduino code to cycle trackball LED color. Add drafts folder.
2018-03-25 Add a reference to Tinkercad Circuits for the MCP23017 test code. Begin creating light controller code for Arduino.
2018-04-08 Add Arduino test code for light strip controller.
2018-04-16 Add Fritzing diagram of the test code for the arcade buttons leds. Rename the same test code.
    [Test MCP23017 Arcade Button LEDs.fzz]
2018-04-16 Add test code the using the light strip and the trackball LEDs.
2019-01-27 Add test code for Raspberry Pi to Arduino I2C communication.
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2019-03-09 Implement a FastLED controller for the trackball tri-color LEDs.
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2019-03-21 Add Fritzing diagram of the light controller.
    [Amiacs Light Controller.fzz]
2019-03-22 Add player LEDs to the wire diagram.
    [Amiacs Light Controller.fzz]
2019-03-22 Add hotkey and exit button LEDs.
    [Amiacs Light Controller.fzz]
2019-03-22 Rename the wire diagram to indicate that it's the breadboard test version.
    [Test Amiacs Light Controller.fzz]
2019-03-24 Add test of arcade button LEDs using 74HC595 as an alternative to I2C and MCP23017.
2019-04-04 Add test of arcade button LEDs using Adafruit TLC5947.
2019-04-11 Update light controller and wire diagram to use TLC5947.
    [Test Amiacs Light Controller.fzz]
2019-05-22 Initial Fritzing diagram of the electronics.
    [Amiacs Arcade.fzz]
2019-05-22 Add player 2 to Fritzing diagram.
    [Amiacs Arcade.fzz]
2019-05-23 Add trackball to Fritzing diagram.
    [Amiacs Arcade.fzz]
2019-08-22 Swap male/female connectors to match actual connections.
    [Amiacs Arcade.fzz]
2019-08-23 Correct trackball wire to be 5V in Fritzing diagram.
    [Amiacs Arcade.fzz]
2019-08-23 Add note that trackball uses common anode.
    [Test Amiacs Light Controller.fzz]
2019-08-23 Correct start and select player light numbers. Change player light exit name to command. Rename cycle player and cycle trackball methods to clarify. Increase trackball indexing rate for testing. Add 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
    [Amiacs_Light_Controller.ino]
2019-08-24 Add power connections between Arduino Nano and LiFePO4wered/Pi+.
    [Amiacs Arcade.fzz]
2019-08-27 Add LiFePO4wered VOUT note.
    [Amiacs Arcade.fzz]
2019-09-28 Add diode to Arduino power source.
    [Amiacs Arcade.fzz]
2019-10-02 Remove zig zag attract display mode. It didn't look good. Add cycle to center attract display mode. Merge a column of player 1 lights.
    [Amiacs_Light_Controller.ino]
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2019-10-21 Add I2C wires to diagram. Add I2C communication test.
    [Amiacs Arcade.fzz]
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2020-02-01 Change display modes to switch to Attract based on time.
2020-02-06 Replace f style formatting. It is not available on Pi's Python version.
    [Amiacs-Event-Processor.py]
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2020-02-09 Enable Pi to Arduino communication. Transfer the light data to the Arduino. Move initializeDisplayMode to a global variable for each mode.
2020-02-09 Correct and improve ROM name handling.
    [Amiacs-Event-Processor.py]
2020-02-09 Correct error where enum value was not being used.
    [Amiacs-Event-Processor.py]
2020-02-09 Correct another place where enum value was not used.
    [Amiacs-Event-Processor.py]
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2020-02-16 Correct class default argument evaluation error.
    [Amiacs-Event-Processor.py]
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2020-02-25 Redesign cycling between player colors.
    [Amiacs_Light_Controller.ino]
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2020-03-18 Change input power to a barrel jack.
    [Amiacs Arcade.fzz]
2020-03-18 Swap Start and Select buttons.
    [Amiacs Arcade.fzz]
2020-09-16 Update Fritzing diagram with monitor cabinet.
    [Amiacs Arcade.fzz]
2020-09-21 Relocate MOSFET trigger module in diagram.
    [Amiacs Arcade.fzz]
2020-09-27 Label the right and left sides of the Fritzing diagram.
    [Amiacs Arcade.fzz]
2020-09-28 Change ambient LED wire color in Fritzing diagram. The colors match actual wire color instead of RGB.
    [Amiacs Arcade.fzz]
2020-09-29 Update Fritzing diagram. Add connectors between LED strips and control modules.
    [Amiacs Arcade.fzz]
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2020-10-02 Update Fritzing diagram. Swap green and blue wires to match actual LED strip.
    [Amiacs Arcade.fzz]
2020-10-03 Add custom jumpers to Fritzing diagram. The jumpers allow easier sharing of Arduino's 5V and GND.
    [Amiacs Arcade.fzz]
2020-10-05 Setup two ambient LED strips. Set color scheme.
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2020-10-06 Add marquee wire connector to Fritzing diagram.
    [Amiacs Arcade.fzz]
2020-10-06 Adjust wire route in Fritzing diagram.
    [Amiacs Arcade.fzz]
2020-10-06 Add warning about connector in Fritzing diagram.
    [Amiacs Arcade.fzz]
2020-10-07 Add brightness potentiometer to Fritzing diagram.
    [Amiacs Arcade.fzz]
2021-03-03 Adjust colors. Change system color to a darker orange. Improve color correction of ambient and trackball so they match colors.
    [Amiacs_Light_Controller.ino]
2021-03-07 Correct I2C data for B and A lights.
    [Amiacs-Event-Processor.py]
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2022-01-12 Add wire information to Fritzing diagram. Increase VIN wire gauge for current requirements.
    [Amiacs Arcade.fzz]
2022-05-01 Add wire lengths to Fritzing diagram.
    [Amiacs Arcade.fzz]
2022-05-10 Add a button and encoder label to place inside the control panel.
2022-05-30 Add notes about button LED wires to Fritzing diagram.
    [Amiacs Arcade.fzz]
2022-05-30 Revise note in Fritzing diagram for clarity.
    [Amiacs Arcade.fzz]
2022-05-31 Flip button label to match Fritzing diagram orientation.
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2022-06-05 Convert inch wire lengths to millimeters.
    [Amiacs Arcade.fzz]
2022-06-11 Add trackball ground wire to Fritzing diagram.
    [Amiacs Arcade.fzz]
2022-06-12 Add encoder wiring note to Fritzing diagram.
    [Amiacs Arcade.fzz]
2022-06-28 Update wire length in Fritzing diagram.
    [Amiacs Arcade.fzz]
2022-07-15 Change brightness potentiometer to 1K in Fritzing diagram.
    [Amiacs Arcade.fzz]
2022-07-15 Replace Drok amplifier with Adafruit MAX9744 on Fritzing diagram.
    [Amiacs Arcade.fzz]
2022-07-31 Change wire length in Fritzing diagram.
    [Amiacs Arcade.fzz]
2022-07-31 Reorder potentiometer wires in Fritzing diagram.
    [Amiacs Arcade.fzz]
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2024-03-11 Update Fritzing diagram version. Add Fritzing diagrams information to the readme.
    [Amiacs Arcade.fzz, Test Amiacs Light Controller.fzz]
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2024-11-22 Update Fritzing diagram with wire length and type.
    [Amiacs Arcade.fzz]
2024-11-26 Add a light test during setup to verify that the RGB colors are correct.
    [Amiacs_Light_Controller.ino]
